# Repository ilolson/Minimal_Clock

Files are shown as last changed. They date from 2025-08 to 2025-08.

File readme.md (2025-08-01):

# Minimal Clock
Small analog style clock made with an STM32 and a 72 LED charlieplex, uses 0201 LED's.
Has 2 buttons and the LSM6DSO IMU as input.
Powered by a CR2032 battery, the battery life lasts about 2-3 days,
this is without any sleep state optimization. 
It is only 28mm in diameter.
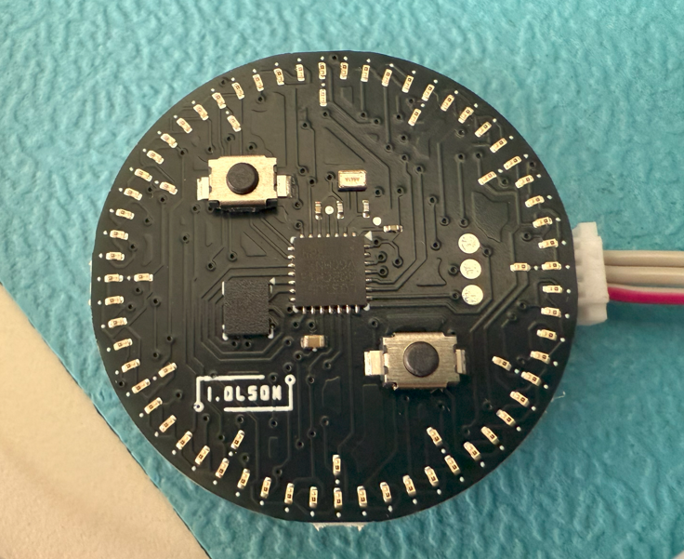
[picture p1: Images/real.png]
The Minimal Clock


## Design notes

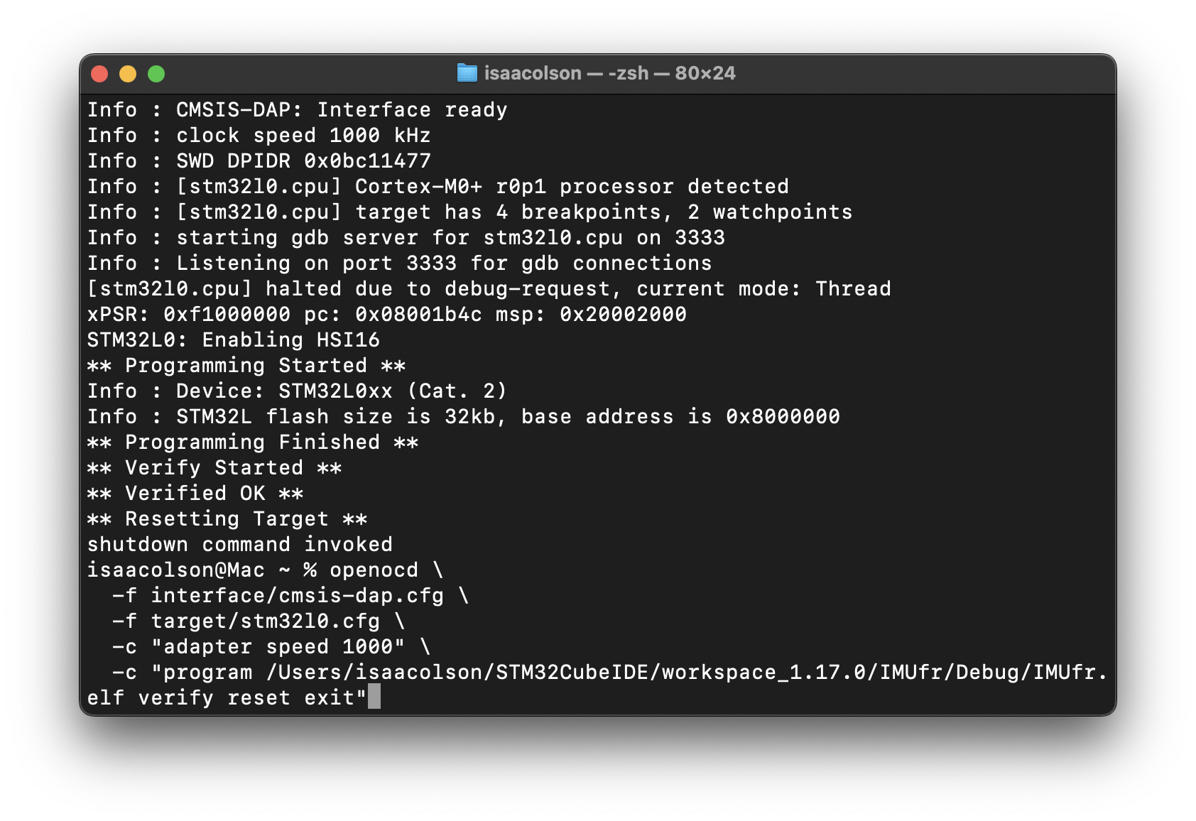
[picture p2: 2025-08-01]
Images/command.png

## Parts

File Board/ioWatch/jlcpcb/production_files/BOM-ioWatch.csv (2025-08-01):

Comment | Designator | Footprint | LCSC | Quantity
ABS05-32.768KHZ-T | Y1 | XTAL_ABS05-32.768KHZ-T | C179633 | 1
LSM6DS0 | U1 | LGA-14_3x2.5mm_P0.5mm_LayoutBorder3x4y | C2829074 | 1
10uf | C5 | C_0402_1005Metric | C315248 | 1
LED | D1,D10,D11,D12,D13,D14,D15,D16,D17,D18,D19,D2,D20,D21,D22,D23,D24,D25,D26,D27,D28,D29,D3,D30,D31,D32,D33,D34,D35,D36,D37,D38,D39,D4,D40,D41,D42,D43,D44,D45,D46,D47,D48,D49,D5,D50,D51,D52,D53,D54,D55,D56,D57,D58,D59,D6,D60,D61,D62,D63,D64,D65,D66,D67,D68,D69,D7,D70,D71,D72,D8,D9 | LED_0201_0603Metric | C3646922 | 72
12pf | C1,C2 | C_0201_0603Metric | C384960 | 2
SW_Push | SW1,SW2 | ts1088 | C720477 | 2
100nf | C3,C4 | C_0201_0603Metric | C76934 | 2
STM32L031G6Ux | U2 | QFN-28_4x4mm_P0.5mm | C96514 | 1
Battery_Cell | BT1 | BatteryHolder_MPD_BC2003_1x2032 |  | 1
Debug | J1 | JST_SH_BM03B-SRSS-TB_1x03-1MP_P1.00mm_Vertical |  | 1

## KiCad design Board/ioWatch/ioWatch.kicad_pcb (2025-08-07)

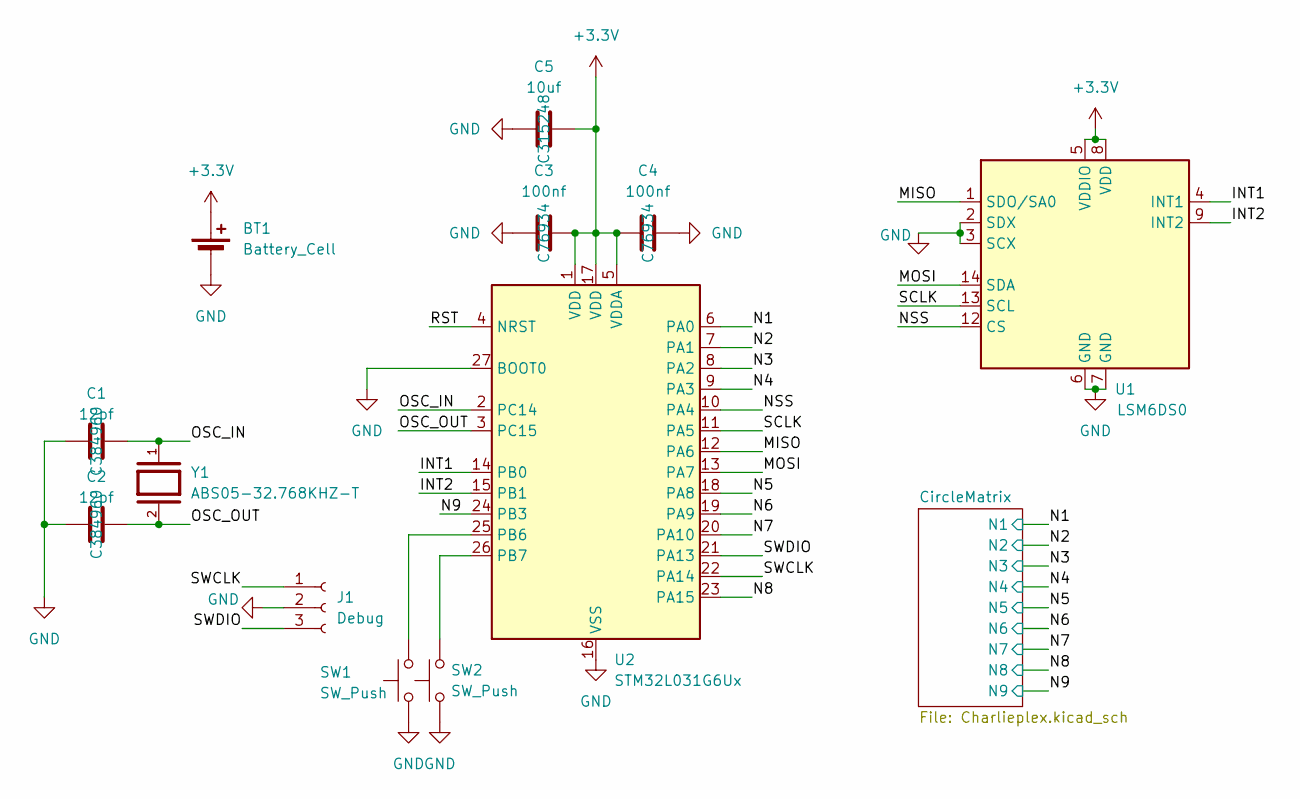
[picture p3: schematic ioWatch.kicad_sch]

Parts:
BT1: Battery_Cell; BatteryHolder_MPD_BC2003_1x2032; LCSC na
C1, C2: 12pf; C_0201_0603Metric; LCSC C384960
C3, C4: 100nf; C_0201_0603Metric; LCSC C76934
C5: 10uf; C_0402_1005Metric; LCSC C315248
J1: Debug; JST_SH_BM03B-SRSS-TB_1x03-1MP_P1.00mm_Vertical; LCSC na
SW1, SW2: SW_Push; ts1088; LCSC C720477
U1: LSM6DS0; LGA-14_3x2.5mm_P0.5mm_LayoutBorder3x4y; LCSC C2829074
U2: STM32L031G6Ux; QFN-28_4x4mm_P0.5mm; LCSC C96514
Y1: ABS05-32.768KHZ-T; XTAL_ABS05-32.768KHZ-T; PARTREV 11/3/2021; LCSC C179633

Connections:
+3.3V: BT1.1 (+), C3.2, C4.1, C5.1, U1.5 (VDDIO), U1.8 (VDD), U2.1 (VDD), U2.5 (VDDA), U2.17 (VDD)
/INT1: U1.4 (INT1), U2.14 (PB0)
/INT2: U1.9 (INT2), U2.15 (PB1)
/MISO: U1.1 (SDO/SA0), U2.12 (PA6)
/MOSI: U1.14 (SDA), U2.13 (PA7)
/N1: U2.6 (PA0); also elsewhere on the board
/N2: U2.7 (PA1); also elsewhere on the board
/N3: U2.8 (PA2); also elsewhere on the board
/N4: U2.9 (PA3); also elsewhere on the board
/N5: U2.18 (PA8); also elsewhere on the board
/N6: U2.19 (PA9); also elsewhere on the board
/N7: U2.20 (PA10); also elsewhere on the board
/N8: U2.23 (PA15); also elsewhere on the board
/N9: U2.24 (PB3); also elsewhere on the board
/NSS: U1.12 (CS), U2.10 (PA4)
/OSC_IN: C1.2, U2.2 (PC14), Y1.1
/OSC_OUT: C2.2, U2.3 (PC15), Y1.2
/RST: U2.4 (NRST)
/SCLK: U1.13 (SCL), U2.11 (PA5)
/SWCLK: J1.1, U2.22 (PA14)
/SWDIO: J1.3, U2.21 (PA13)
GND: BT1.2 (-), C1.1, C2.1, C3.1, C4.2, C5.2, J1.2, SW1.1, SW2.1, U1.2 (SDX), U1.3 (SCX), U1.6 (GND), U1.7 (GND), U2.16 (VSS), U2.27 (BOOT0), U2.28 (VSS)
unnamed: SW1.2, U2.25 (PB6)
unnamed: SW2.2, U2.26 (PB7)

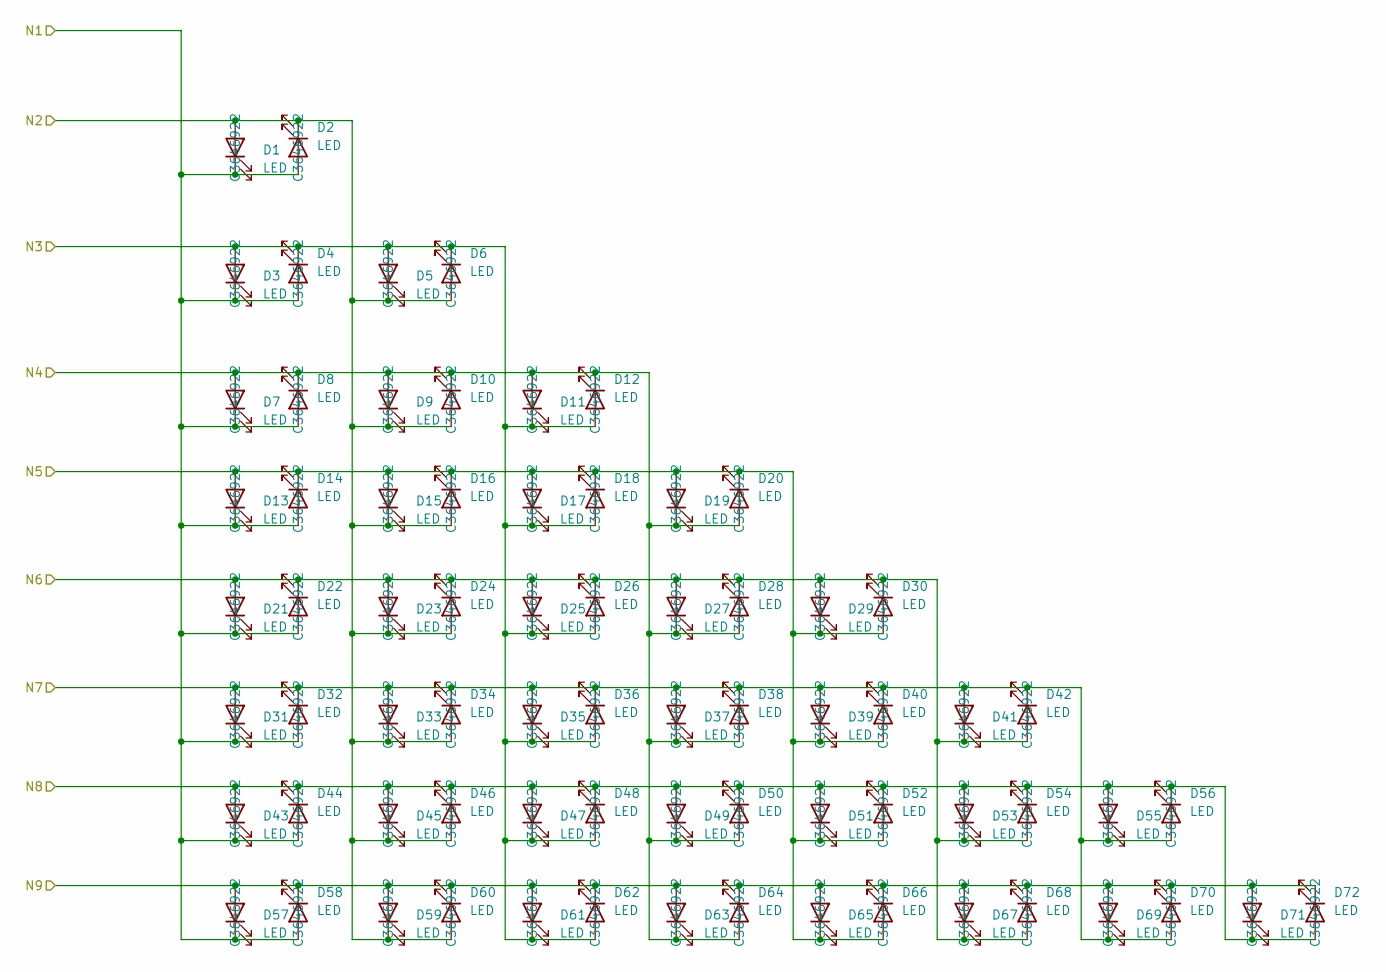
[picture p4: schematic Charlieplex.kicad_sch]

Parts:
D1, D2, D3, D4, D5, D6, D7, D8, D9, D10, D11, D12, D13, D14, D15, D16, D17, D18, D19, D20, D21, D22, D23, D24, D25, D26, D27, D28, D29, D30, D31, D32, D33, D34, D35, D36, D37, D38, D39, D40, D41, D42, D43, D44, D45, D46, D47, D48, D49, D50, D51, D52, D53, D54, D55, D56, D57, D58, D59, D60, D61, D62, D63, D64, D65, D66, D67, D68, D69, D70, D71, D72: LED; LED_0201_0603Metric; LCSC C3646922

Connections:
/N1: D1.1 (K), D2.2 (A), D3.1 (K), D4.2 (A), D7.1 (K), D8.2 (A), D13.1 (K), D14.2 (A), D21.1 (K), D22.2 (A), D31.1 (K), D32.2 (A), D43.1 (K), D44.2 (A), D57.1 (K), D58.2 (A); also elsewhere on the board
/N2: D1.2 (A), D2.1 (K), D5.1 (K), D6.2 (A), D9.1 (K), D10.2 (A), D15.1 (K), D16.2 (A), D23.1 (K), D24.2 (A), D33.1 (K), D34.2 (A), D45.1 (K), D46.2 (A), D59.1 (K), D60.2 (A); also elsewhere on the board
/N3: D3.2 (A), D4.1 (K), D5.2 (A), D6.1 (K), D11.1 (K), D12.2 (A), D17.1 (K), D18.2 (A), D25.1 (K), D26.2 (A), D35.1 (K), D36.2 (A), D47.1 (K), D48.2 (A), D61.1 (K), D62.2 (A); also elsewhere on the board
/N4: D7.2 (A), D8.1 (K), D9.2 (A), D10.1 (K), D11.2 (A), D12.1 (K), D19.1 (K), D20.2 (A), D27.1 (K), D28.2 (A), D37.1 (K), D38.2 (A), D49.1 (K), D50.2 (A), D63.1 (K), D64.2 (A); also elsewhere on the board
/N5: D13.2 (A), D14.1 (K), D15.2 (A), D16.1 (K), D17.2 (A), D18.1 (K), D19.2 (A), D20.1 (K), D29.1 (K), D30.2 (A), D39.1 (K), D40.2 (A), D51.1 (K), D52.2 (A), D65.1 (K), D66.2 (A); also elsewhere on the board
/N6: D21.2 (A), D22.1 (K), D23.2 (A), D24.1 (K), D25.2 (A), D26.1 (K), D27.2 (A), D28.1 (K), D29.2 (A), D30.1 (K), D41.1 (K), D42.2 (A), D53.1 (K), D54.2 (A), D67.1 (K), D68.2 (A); also elsewhere on the board
/N7: D31.2 (A), D32.1 (K), D33.2 (A), D34.1 (K), D35.2 (A), D36.1 (K), D37.2 (A), D38.1 (K), D39.2 (A), D40.1 (K), D41.2 (A), D42.1 (K), D55.1 (K), D56.2 (A), D69.1 (K), D70.2 (A); also elsewhere on the board
/N8: D43.2 (A), D44.1 (K), D45.2 (A), D46.1 (K), D47.2 (A), D48.1 (K), D49.2 (A), D50.1 (K), D51.2 (A), D52.1 (K), D53.2 (A), D54.1 (K), D55.2 (A), D56.1 (K), D71.1 (K), D72.2 (A); also elsewhere on the board
/N9: D57.2 (A), D58.1 (K), D59.2 (A), D60.1 (K), D61.2 (A), D62.1 (K), D63.2 (A), D64.1 (K), D65.2 (A), D66.1 (K), D67.2 (A), D68.1 (K), D69.2 (A), D70.1 (K), D71.2 (A), D72.1 (K); also elsewhere on the board

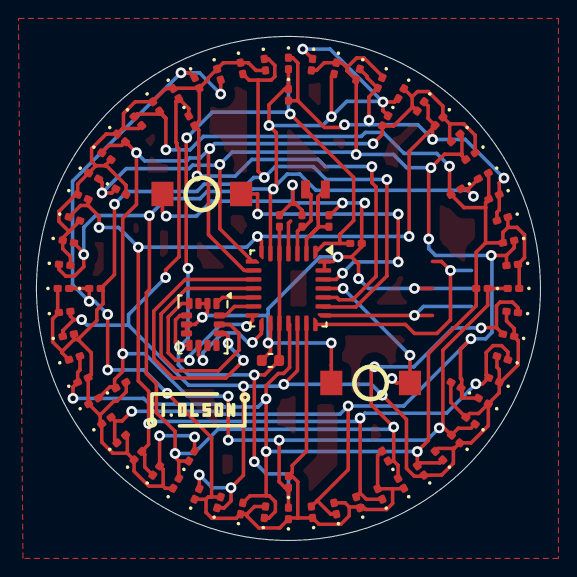
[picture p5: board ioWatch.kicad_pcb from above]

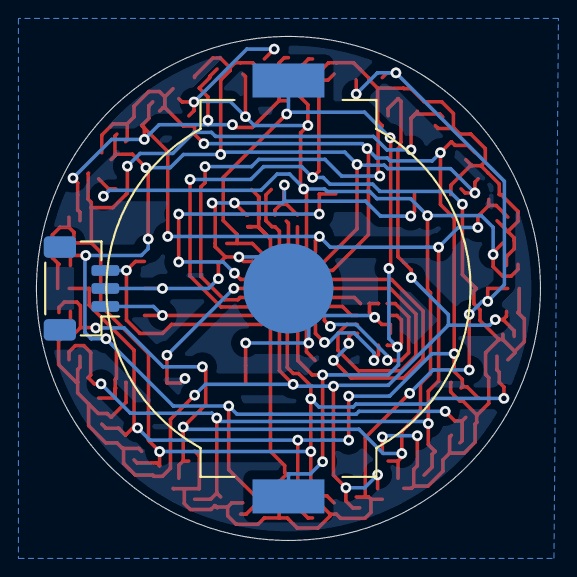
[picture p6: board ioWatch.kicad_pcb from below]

Board: 2 copper layers, 28.0 x 28.0 mm, 84 parts (2 on the bottom side), 23 nets.
